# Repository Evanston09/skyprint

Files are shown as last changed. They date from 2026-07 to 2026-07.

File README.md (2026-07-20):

# Skyprint

Skyprint is an ESP32 desk display that presents the closest airborne aircraft
as a quiet monochrome identification plaque. It deliberately avoids maps,
tracks, and radar styling.

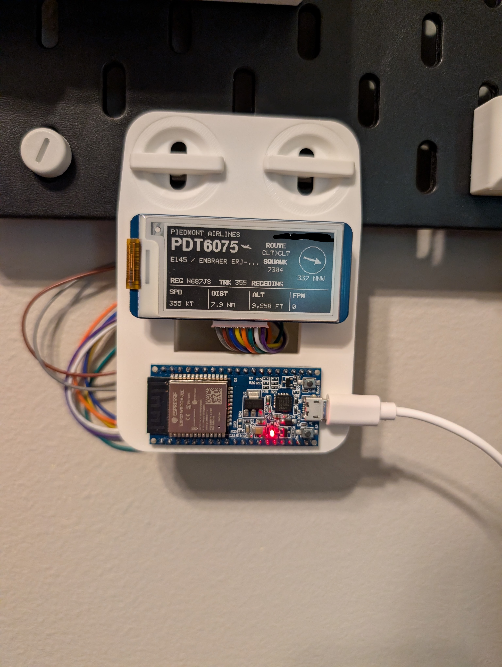
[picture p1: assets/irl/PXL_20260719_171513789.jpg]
Skyprint displaying live aircraft information


## Hardware and wiring

- Inland 38-pin ESP32 development board
- Waveshare 2.13-inch V4 black-and-white e-paper display
- 250 x 122 visible pixels, SSD1680 controller
- Stable USB power supply

Connect the display with power removed:

| Display | ESP32 |
| --- | ---: |
| DIN / MOSI | GPIO 14 |
| CLK | GPIO 27 |
| CS | GPIO 26 |
| DC | GPIO 25 |
| RST | GPIO 33 |
| BUSY | GPIO 32 |
| VCC | 3.3 V |
| GND | GND |

## Configuration

Copy the example and edit the private copy:

```sh
cp include/config.example.h include/config.h
```

Set the 2.4 GHz Wi-Fi credentials, office latitude/longitude, and change
`SKYPRINT_CONFIGURED` to `1`. `include/config.h` is ignored by git. Building
without a completed private configuration intentionally fails with a clear
compiler message.

Set `SKYPRINT_DISPLAY_HEADING_DEGREES` to the compass direction represented by
an UP arrow on the screen. Use the direction you face when looking straight
ahead over the display: north is `0`, east `90`, south `180`, and west `270`.
For example, if the display sits at an east-facing office window, use `90`.
The LOOK arrow then rotates by `aircraft bearing - display heading`, so it
points left, right, ahead, or behind relative to the physical display.

Set `SKYPRINT_INVERT_DISPLAY` to `1` for a black background with white text,
rules, logos, and direction graphics. Leave it at `0` for the standard white
background. Inverted mode changes only the palette; layout and refresh policy
stay the same. A mostly black image may make e-paper ghosting more noticeable.

The configured coordinates are sent to ADSB.lol in each radius query. ADSB.lol
is a third-party community service whose availability and access policy can
change. This firmware is intended for personal, non-commercial use.

When a new aircraft portrait is selected, its callsign and live coordinates
are sent to ADSB.lol's position-aware route endpoint. ADSB.lol sometimes
returns a multi-leg or round-trip itinerary such as `CLT-LGA-CLT`; Skyprint
uses the live position and heading to select the current leg instead of
incorrectly collapsing that itinerary to `CLT>CLT`. The selected leg is also
checked locally against the airport coordinates, which protects against stale
callsign plausibility-cache results. Rejected or unknown routes show `N/A`.
The ICAO address and callsign are also sent to the
[ADSBDB API](https://www.adsbdb.com/) for the manufacturer/full model name and
the airline/radio telephony identity. That identity replaces the generic
top-left caption—for example, `BLUE STREAK / PSA AIRLINES` for a JIA flight.
Metadata may be missing or incorrect, and lookup failures never affect aircraft
selection. Temporary failures are retried after five minutes; the caption falls
back to `NEAREST AIRBORNE` when no airline identity is available.

### Airline logos

Airline logos are selected from the first three letters of the flight callsign,
which normally contain its ICAO airline designator. Put transparent PNG source
files in `assets/logos` using names such as `AAL.png`, `DAL.png`, and `UAL.png`.
`default.png` is used for private, military, or otherwise unknown operators.

After adding or replacing PNGs, regenerate the 16 x 16 monochrome firmware
assets and rebuild:

```sh
python3 tools/generate_airline_logos.py
pio run -e esp32dev
```

The converter requires ImageMagick's `magick` command. Generated bitmap code is
checked in, so ImageMagick is not required for ordinary firmware builds.

## Build, upload, and monitor

```sh
pio run -e esp32dev
pio run -e esp32dev -t upload
pio device monitor -b 115200
```

## Behavior

The device scans a 25 NM radius every 20 seconds. It accepts only aircraft with
a numeric airborne altitude, a position no more than 30 seconds old, and
coordinates inside the radius. Distance and true bearing are calculated on the
ESP32.

The current portrait remains selected until the same challenger is at least 20
percent and 0.5 NM closer in two consecutive scans. A selected aircraft must be
missing from two successful scans before it is replaced or the screen changes
to Clear Sky. Network and API failures never count as missing-aircraft scans.

The plaque refreshes changing details at most once per minute. Same-aircraft
updates use fast partial refresh; identity and status changes use full refresh.
A full refresh also occurs after five partial refreshes and once every 24 hours.
Data labels use a consistent bold weight while the `NEAREST AIRBORNE` caption
and live values remain regular for quick visual separation.

- `SCANNING`: startup, clock synchronization, or no valid data for five minutes
- `CLEAR SKY`: a successful scan found no eligible aircraft
- Aircraft plaque: callsign, type/description, registration, altitude,
  groundspeed, distance, bearing, aircraft heading/track, and signed vertical
  rate. The full aircraft type sits beneath the callsign with deliberate
  spacing above and below the large identity text, while the
  registration/heading/motion row sits immediately above the metrics divider.
  The bottom metrics are ordered `SPD`, `DIST`, `ALT`, and `FPM`; bearing
  appears without a label beneath the direction roundel. A compact motion state
  immediately after the heading/track reads `CLOSING`, `CLOSEST`, or `RECEDING`
  based on successive distances from the configured location; it reads
  `TRACKING` until a trend is known. Rates within 200 FPM
  of level are presented as `0`; barometric rate is preferred with geometric
  rate as a fallback. A calibrated LOOK arrow points from the office toward the
  aircraft. The plaque also includes a compact published route block
  labeled `ROUTE` with `BNA>FLL` beneath it beside the callsign when available.
  Missing routes show `N/A`; the aircraft squawk code
  appears below a bold `SQUAWK` label. The upper-right corner shows the UTC date
  and last successful live aircraft update on one aviation-style line, such as
  `19JUL 14:37Z`.

Serial output reports the assigned IP address, signal strength, active DNS
server, Wi-Fi retries, API errors, valid aircraft counts, selection changes,
and full refreshes without printing credentials. Because the display is
continuously powered, Wi-Fi power saving is disabled for connection stability.
Cloudflare and Google DNS are configured instead of relying on a potentially
unreliable router DNS proxy. Three consecutive DNS or connection failures
trigger an automatic Wi-Fi link reset; they never count as aircraft misses.

## Hardware acceptance checklist

1. Confirm the first screen is landscape and all content fits within 250 x 122.
2. Confirm BUSY completes both full and partial updates without hanging.
3. Compare one live result with ADSB.lol for the configured point.
4. Confirm the LOOK arrow points up when aircraft bearing equals the configured
   display heading, right at heading + 90, and left at heading - 90.
5. Disconnect Wi-Fi: the last portrait should remain for five minutes, then
   change once to Scanning. Reconnect and confirm automatic recovery.
6. Temporarily use a remote location with no traffic to verify Clear Sky.
7. Observe six same-aircraft updates and confirm the sixth is a full refresh.

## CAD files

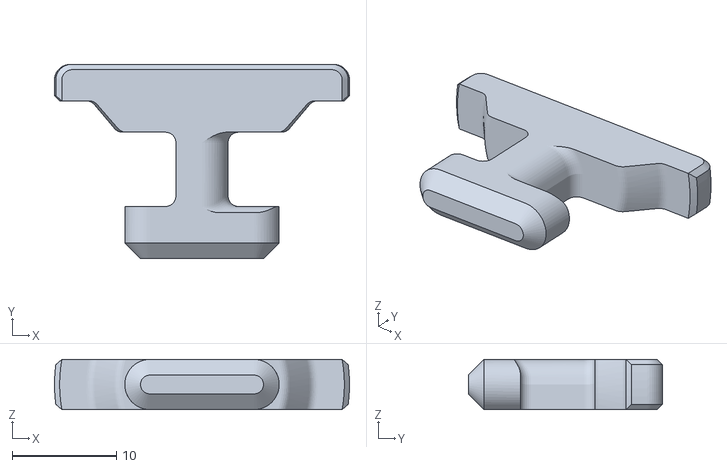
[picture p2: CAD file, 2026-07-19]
assets/models/T-Clip for Unpainted Skadis.stl
28.3 x 18.6 x 4.80

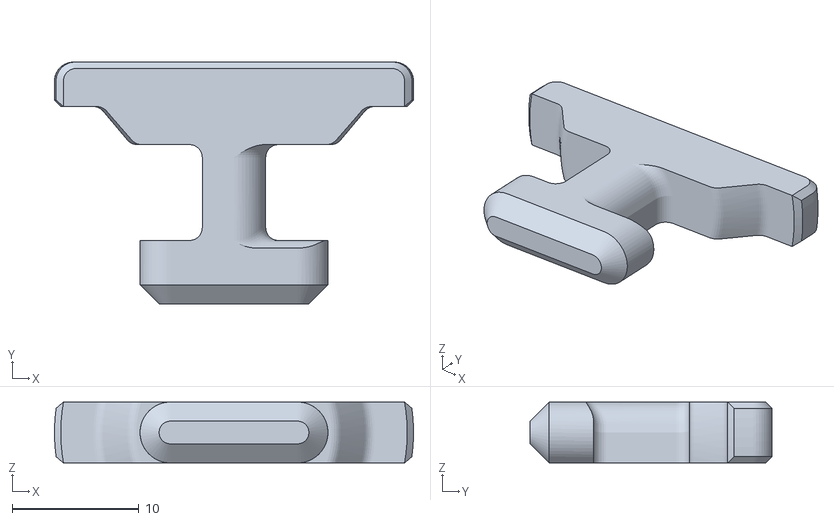
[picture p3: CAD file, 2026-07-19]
assets/models/T-Clip for Painted Skadis.stl
28.3 x 19.1 x 4.80

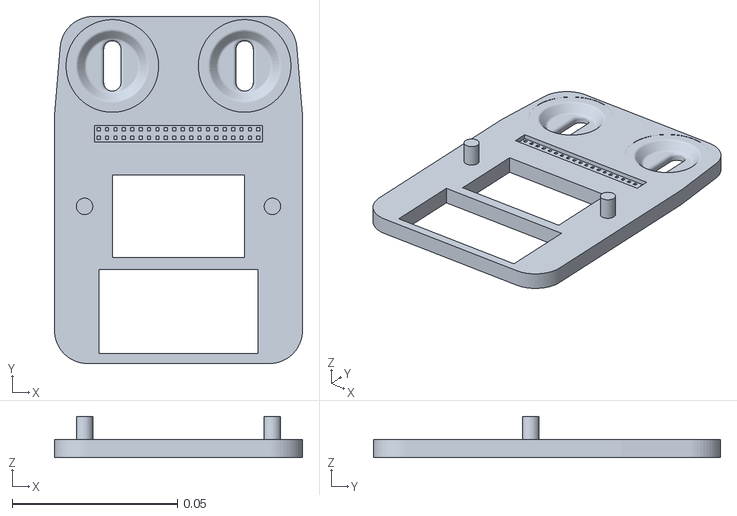
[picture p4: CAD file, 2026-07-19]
assets/models/Skadis Plate.stl
0.075 x 0.105 x 0.0125

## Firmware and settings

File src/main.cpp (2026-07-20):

#include <Arduino.h>
#include <WiFi.h>

#include <ctime>

#if __has_include("config.h")
#include "config.h"
#else
#error "Missing include/config.h. Copy include/config.example.h and fill in your Wi-Fi and office coordinates."
#endif

#if !defined(SKYPRINT_CONFIGURED) || SKYPRINT_CONFIGURED != 1
#error "Set SKYPRINT_CONFIGURED to 1 in include/config.h after filling in its values."
#endif

#ifndef SKYPRINT_DISPLAY_HEADING_DEGREES
#error "Set SKYPRINT_DISPLAY_HEADING_DEGREES in include/config.h; see config.example.h."
#endif

#ifndef SKYPRINT_INVERT_DISPLAY
#error "Set SKYPRINT_INVERT_DISPLAY in include/config.h; see config.example.h."
#endif

#include "aircraft.h"
#include "aircraft_client.h"
#include "display_ui.h"
#include "route_client.h"
#include "settings.h"

namespace {

static_assert(SKYPRINT_DISPLAY_HEADING_DEGREES >= 0 &&
                  SKYPRINT_DISPLAY_HEADING_DEGREES < 360,
              "SKYPRINT_DISPLAY_HEADING_DEGREES must be from 0 through 359");
static_assert(SKYPRINT_INVERT_DISPLAY == 0 || SKYPRINT_INVERT_DISPLAY == 1,
              "SKYPRINT_INVERT_DISPLAY must be 0 or 1");

skyprint::AdsbLolClient aircraftClient;
skyprint::AircraftSelector aircraftSelector;
skyprint::DisplayUi displayUi;
skyprint::AviationMetadataClient metadataClient;
skyprint::RouteInfo currentRoute;
std::string currentAircraftName;

uint32_t lastPollAt = 0;
uint32_t lastSuccessfulPollAt = 0;
uint32_t lastPortraitRenderAt = 0;
uint32_t lastWifiAttemptAt = 0;
uint32_t wifiRetryIntervalMs = 5000;
uint32_t lastRouteAttemptAt = 0;
uint32_t lastAircraftNameAttemptAt = 0;
time_t lastSuccessfulPollUtc = 0;
uint8_t consecutiveNetworkFailures = 0;
bool hasSuccessfulPoll = false;
bool wifiConnectionReported = false;
bool routeLookupCompleted = false;
std::string routeCallsign;
bool aircraftNameLookupCompleted = false;
std::string aircraftNameHex;

bool elapsed(uint32_t now, uint32_t since, uint32_t interval) {
  return static_cast<uint32_t>(now - since) >= interval;
}

void beginWifi(uint32_t now) {
  Serial.printf("[wifi] connecting to %s\n", SKYPRINT_WIFI_SSID);
  WiFi.mode(WIFI_STA);
  WiFi.setSleep(false);
  WiFi.setAutoReconnect(true);
  // Keep DHCP addressing while using resolvers that are independent of the
  // router's frequently unreliable DNS proxy.
  WiFi.config(INADDR_NONE, INADDR_NONE, INADDR_NONE, IPAddress(1, 1, 1, 1),
              IPAddress(8, 8, 8, 8));
  WiFi.begin(SKYPRINT_WIFI_SSID, SKYPRINT_WIFI_PASSWORD);
  lastWifiAttemptAt = now;
}

void maintainWifi(uint32_t now) {
  if (WiFi.status() == WL_CONNECTED) {
    wifiRetryIntervalMs = 5000;
    if (!wifiConnectionReported) {
      const String localIp = WiFi.localIP().toString();
      const String dnsIp = WiFi.dnsIP().toString();
      Serial.printf("[wifi] connected ip=%s rssi=%d dBm dns=%s\n",
                    localIp.c_str(), WiFi.RSSI(), dnsIp.c_str());
      wifiConnectionReported = true;
    }
    return;
  }
  wifiConnectionReported = false;
  if (!elapsed(now, lastWifiAttemptAt, wifiRetryIntervalMs)) return;

  Serial.println("[wifi] reconnecting");
  WiFi.disconnect(false, false);
  WiFi.begin(SKYPRINT_WIFI_SSID, SKYPRINT_WIFI_PASSWORD);
  lastWifiAttemptAt = now;
  wifiRetryIntervalMs = min<uint32_t>(wifiRetryIntervalMs * 2UL, 60000UL);
}

void renderCurrentAircraft(bool forceFull, uint32_t now) {
  const skyprint::Aircraft* current = aircraftSelector.current();
  if (current == nullptr) return;
  skyprint::Aircraft portrait = *current;
  if (!currentAircraftName.empty()) {
    portrait.description = currentAircraftName;
  }
  displayUi.showAircraft(portrait, currentRoute,
                         SKYPRINT_DISPLAY_HEADING_DEGREES,
                         lastSuccessfulPollUtc, forceFull);
  lastPortraitRenderAt = now;
}

bool fetchAircraftNameForCurrent(uint32_t now, bool newAircraft) {
  const skyprint::Aircraft* current = aircraftSelector.current();
  if (current == nullptr) return false;
  const std::string previousName = currentAircraftName;
  const bool identityChanged = newAircraft || aircraftNameHex != current->hex;
  if (identityChanged) {
    currentAircraftName.clear();
    aircraftNameHex = current->hex;
    aircraftNameLookupCompleted = false;
    lastAircraftNameAttemptAt = 0;
  }

  if (current->description != "TYPE UNKNOWN" &&
      current->description != current->typeCode) {
    currentAircraftName = current->description;
    aircraftNameLookupCompleted = true;
    return currentAircraftName != previousName;
  }

  if (aircraftNameLookupCompleted ||
      (!identityChanged && lastAircraftNameAttemptAt != 0 &&
       !elapsed(now, lastAircraftNameAttemptAt,
                skyprint::settings::kMetadataRetryIntervalMs))) {
    return currentAircraftName != previousName;
  }

  lastAircraftNameAttemptAt = now;
  const skyprint::AircraftNameFetchResult nameFetch =
      metadataClient.fetchAircraftName(current->hex);
  aircraftNameLookupCompleted = nameFetch.completed;
  if (!nameFetch.fullName.empty()) {
    currentAircraftName = nameFetch.fullName;
    Serial.printf("[aircraft] %s / %s\n", current->typeCode.c_str(),
                  currentAircraftName.c_str());
  } else {
    Serial.printf("[aircraft] %s\n", nameFetch.error.c_str());
  }
  return currentAircraftName != previousName;
}

void fetchRouteForCurrent(uint32_t now, bool newAircraft) {
  const skyprint::Aircraft* current = aircraftSelector.current();
  if (current == nullptr) return;
  const bool routeIdentityChanged =
      newAircraft || routeCallsign != current->callsign;
  if (routeIdentityChanged) {
    currentRoute = {};
    routeCallsign = current->callsign;
    routeLookupCompleted = false;
  }
  if (routeLookupCompleted ||
      (!routeIdentityChanged && lastRouteAttemptAt != 0 &&
       !elapsed(now, lastRouteAttemptAt,
                skyprint::settings::kMetadataRetryIntervalMs))) {
    return;
  }

  lastRouteAttemptAt = now;
  const skyprint::RouteFetchResult routeFetch = metadataClient.fetchRoute(
      current->callsign, current->latitude, current->longitude,
      current->hasHeading, current->headingDeg);
  routeLookupCompleted = routeFetch.completed;
  if (routeFetch.completed || routeFetch.route.available() ||
      routeFetch.route.hasAirlineIdentity()) {
    currentRoute = routeFetch.route;
  }
  if (routeFetch.route.available()) {
    Serial.printf("[route] %s > ", currentRoute.origin.c_str());
    if (!currentRoute.midpoint.empty()) {
      Serial.printf("%s > ", currentRoute.midpoint.c_str());
    }
    Serial.println(currentRoute.destination.c_str());
  } else {
    Serial.printf("[route] %s\n", routeFetch.error.c_str());
  }
  if (routeFetch.route.hasAirlineIdentity()) {
    Serial.printf("[airline] %s / %s\n",
                  routeFetch.route.airlineCallsign.c_str(),
                  routeFetch.route.airlineName.c_str());
  }
}

void handleSuccessfulPoll(const skyprint::FetchResult& fetch, uint32_t now) {
  hasSuccessfulPoll = true;
  lastSuccessfulPollAt = now;
  lastSuccessfulPollUtc = std::time(nullptr);
  const skyprint::DistanceTrend previousDistanceTrend =
      aircraftSelector.current() == nullptr
          ? skyprint::DistanceTrend::kUnknown
          : aircraftSelector.current()->distanceTrend;
  const skyprint::SelectionEvent event =
      aircraftSelector.ingestSuccessfulScan(fetch.aircraft);
  const bool distanceTrendChanged =
      aircraftSelector.current() != nullptr &&
      aircraftSelector.current()->distanceTrend != previousDistanceTrend;

  Serial.printf("[adsb] valid aircraft: %u\n",
                static_cast<unsigned>(fetch.aircraft.size()));
  switch (event) {
    case skyprint::SelectionEvent::kSelected:
    case skyprint::SelectionEvent::kSwitched:
      Serial.printf("[select] portrait %s\n",
                    aircraftSelector.current()->hex.c_str());
      fetchAircraftNameForCurrent(now, true);
      fetchRouteForCurrent(now, true);
      renderCurrentAircraft(true, now);
      break;
    case skyprint::SelectionEvent::kUpdated: {
      const bool aircraftNameChanged =
          fetchAircraftNameForCurrent(now, false);
      fetchRouteForCurrent(now, false);
      if (displayUi.screenKind() != skyprint::ScreenKind::kAircraft) {
        renderCurrentAircraft(true, now);
      } else if (aircraftNameChanged || distanceTrendChanged) {
        renderCurrentAircraft(false, now);
      } else if (elapsed(now, lastPortraitRenderAt,
                         skyprint::settings::kPortraitRefreshIntervalMs)) {
        renderCurrentAircraft(false, now);
      }
      break;
    }
    case skyprint::SelectionEvent::kCleared:
      if (displayUi.screenKind() != skyprint::ScreenKind::kClearSky) {
        Serial.println("[select] clear sky");
        displayUi.showClearSky(true);
      }
      break;
    case skyprint::SelectionEvent::kNone:
      Serial.printf("[select] current aircraft missing (%u/%u)\n",
                    aircraftSelector.missingCount(),
                    skyprint::settings::kMissingConfirmations);
      break;
  }
}

void pollAircraft(uint32_t now) {
  lastPollAt = now;
  const skyprint::FetchResult fetch = aircraftClient.fetchNearby(
      SKYPRINT_OFFICE_LATITUDE, SKYPRINT_OFFICE_LONGITUDE,
      skyprint::settings::kSearchRadiusNm);
  if (!fetch.success) {
    Serial.printf("[adsb] %s\n", fetch.error.c_str());
    const bool networkFailure =
        fetch.failure == skyprint::FetchFailure::kDns ||
        fetch.failure == skyprint::FetchFailure::kConnection;
    if (networkFailure) {
      ++consecutiveNetworkFailures;
      if (consecutiveNetworkFailures >=
          skyprint::settings::kNetworkFailuresBeforeReconnect) {
        Serial.println("[wifi] repeated network failures; resetting link");
        WiFi.disconnect(false, false);
        wifiConnectionReported = false;
        lastWifiAttemptAt = now - wifiRetryIntervalMs;
        consecutiveNetworkFailures = 0;
      }
    } else {
      consecutiveNetworkFailures = 0;
    }
    return;
  }
  consecutiveNetworkFailures = 0;
  handleSuccessfulPoll(fetch, now);
}

void redrawCurrentScreenFull(uint32_t now) {
  switch (displayUi.screenKind()) {
    case skyprint::ScreenKind::kAircraft:
      renderCurrentAircraft(true, now);
      break;
    case skyprint::ScreenKind::kClearSky:
      displayUi.showClearSky(true);
      break;
    case skyprint::ScreenKind::kScanning:
      displayUi.showScanning(true);
      break;
  }
}

}  // namespace

void setup() {
  Serial.begin(115200);
  delay(100);
  Serial.println("\nSkyprint closest-aircraft display");

  displayUi.begin();
  displayUi.showScanning(true);
  configTime(0, 0, "pool.ntp.org", "time.nist.gov");
  beginWifi(millis());
}

void loop() {
  const uint32_t now = millis();
  maintainWifi(now);

  if (WiFi.status() == WL_CONNECTED &&
      (lastPollAt == 0 ||
       elapsed(now, lastPollAt, skyprint::settings::kPollIntervalMs))) {
    pollAircraft(now);
  }

  if (hasSuccessfulPoll &&
      elapsed(now, lastSuccessfulPollAt,
              skyprint::settings::kDataStaleAfterMs) &&
      displayUi.screenKind() != skyprint::ScreenKind::kScanning) {
    Serial.println("[state] live data stale; scanning");
    displayUi.showScanning(true);
  }

  if (displayUi.needsDailyFullRefresh(now)) {
    Serial.println("[display] scheduled full refresh");
    redrawCurrentScreenFull(now);
  }

  delay(25);
}

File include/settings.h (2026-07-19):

#pragma once

#include <stdint.h>

namespace skyprint {
namespace settings {

constexpr int kMosiPin = 14;
constexpr int kClockPin = 27;
constexpr int kChipSelectPin = 26;
constexpr int kDataCommandPin = 25;
constexpr int kResetPin = 33;
constexpr int kBusyPin = 32;

constexpr int kVisibleWidth = 250;
constexpr int kVisibleHeight = 122;

constexpr char kApiBaseUrl[] = "https://api.adsb.lol/v2/point";
constexpr char kAdsbLolRouteApiBaseUrl[] =
    "https://api.adsb.lol/api/0/route";
constexpr char kApiHostname[] = "api.adsb.lol";
constexpr uint16_t kApiPort = 443;
constexpr char kAdsbDbRouteApiBaseUrl[] =
    "https://api.adsbdb.com/v0/callsign";
constexpr char kAdsbDbAircraftApiBaseUrl[] =
    "https://api.adsbdb.com/v0/aircraft";
constexpr char kAdsbDbApiHostname[] = "api.adsbdb.com";
constexpr uint16_t kAdsbDbApiPort = 443;
constexpr double kSearchRadiusNm = 25.0;
constexpr double kMaximumPositionAgeSeconds = 30.0;

constexpr uint32_t kPollIntervalMs = 20UL * 1000UL;
constexpr uint32_t kPortraitRefreshIntervalMs = 60UL * 1000UL;
constexpr uint32_t kDataStaleAfterMs = 5UL * 60UL * 1000UL;
constexpr uint32_t kDailyFullRefreshMs = 24UL * 60UL * 60UL * 1000UL;
constexpr uint32_t kTlsHandshakeTimeoutSeconds = 15;
constexpr uint32_t kHttpConnectTimeoutMs = 15UL * 1000UL;
constexpr uint32_t kHttpResponseTimeoutMs = 30UL * 1000UL;
constexpr uint32_t kMetadataRetryIntervalMs = 5UL * 60UL * 1000UL;
constexpr uint8_t kNetworkFailuresBeforeReconnect = 3;

constexpr double kChallengerDistanceRatio = 0.80;
constexpr double kMinimumSwitchAdvantageNm = 0.5;
constexpr double kDistanceTrendDeadbandNm = 0.05;
constexpr uint8_t kChallengerConfirmations = 2;
constexpr uint8_t kMissingConfirmations = 2;
constexpr uint8_t kClosestPointHoldPolls = 2;

}  // namespace settings
}  // namespace skyprint

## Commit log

2026-07-19 Add project photo and 3D models
    [Skadis Plate.stl, T-Clip for Painted Skadis.stl, T-Clip for Unpainted Skadis.stl]
2026-07-20 Select current ADSB.lol route leg by position and heading
    - Add local published-route leg selection to handle round trips like CLT-LGA-CLT
    - Validate selected legs against airport coordinates to reject stale or implausible routes
    - Pass aircraft heading into route fetches and cover leg selection with tests
